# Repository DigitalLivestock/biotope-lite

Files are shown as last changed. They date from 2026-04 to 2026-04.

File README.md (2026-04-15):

# BIOTOPE(LITE)™

> BIOTOPE(LITE)™: a High Precision Environment Monitoring Unit




---

## A Bit of History
I started this project a couple of years ago and almost finished it, but life got in the way. Recently, I decided it was time to tie up the loose ends and complete it. While the initial development was paused, the recent work focused on finalizing the essential functionality. Some cleaning of code and its structure was performed, but some of the hacky parts still remain. The main goal of the project was to build an embedded solution based on an AVR microcontroller, designing and implementing as much of the supporting electronics from scratch as possible.

---

## About

The BIOTOPE(LITE)™ is a high precision monitoring unit for measuring indoor and outdoor temperature, relative humidity and pressure. Measurements are displayed on the built-in LCD screen, presenting current, maximum and minimum for data with smart backlight. Navigation among data is enabled by available buttons. Measured maximum and minimum are automatically restored between power on and -off. Through available settings, it is possible to manually store and reset data.



## Features

* Indoor temperature reading in range (-)40 – 85 °C.
* Indoor pressure readings in range 300 – 1100 hPa.
* Indoor relative humidity as 0 – 100 %.
* Outdoor temperature reading in range (-)25 – 125 °C.
* Minimum and maximum tracking of temperature, humidity and pressure.
* LCD display with timer based backlight.
* Buttons for navigation and configuration.
* Persistent data store and restore between power states.
* Ultra low power consumption at 15mA when idle or 23 mA when active.
* Battery (4 x AA) or wall powered (0.2A/6V via 2.1 mm DC-Jack).

---

## Usage
Choose if you want to use 4 x AA batteries or a compatible wall power adapter capable of supplying at least 0.2A at 6V via DC-Jack (2.1 mm):
* Battery powered: carefully open BIOTOPE(LITE)™ by unscrewing the back panel and inserting 4 x AA batteries into the battery holder.
* Wall power adapter: connect adapter DC-Jack male contact to BIOTOPE(LITE)™ female.
Power-on device by moving switch above DC-Jack female connector. The LCD screen shall light-up showing initial start-up screen. 

The device displays measurement data and configuration options on the LCD screen in the form of frames, among which a user can navigate using buttons. As can be seen in the next figure below, a frame is made up of two rows and there are five buttons available. Buttons consist of UP, DOWN, LEFT, RIGHT, and ENTER—allowing for full access among network of selectable frames, as can be observed in the second figure. Frames can be seen connected to one another via arrows, here representing button actions.



In the following, each frame and their functions are explained more in detail. The identification numbers of each Frame are found in the green boxes inserted at top-right of each frame in the following figure.
* Frame 0.0: Initial – Device name and software version 
* Frame 1.0: Current temperature indoors and outdoors (°C)
* Frame 1.1: Maximum and minimum temperature indoors (°C)
* Frame 1.2: Maximum and minimum temperature outdoors (°C)
* Frame 2.0: Current relative humidity (%) and pressure (hPa) indoors
* Frame 2.1: Maximum and minimum relative humidity indoors (%)
* Frame 2.2: Maximum and minimum pressure indoors (hPa)
* Frame 3.0: Settings menu
* Frame 3.1: Backup all maximum and minimum data using persistent storage when pressing ENTER-button
* Frame 3.2: Reset all maximum and minimum data in persistent storage when pressing ENTER-button



---

## Project Structure

```
biotope-lite/
├── src/
│ └── biotope_lite/
│     ├── biotope_lite.ino
│     ├── biotope_lite_app.h
│     ├── biotope_lite_app.cpp
│     ├── config.h
│     ├── lcd.h 
│     ├── lcd.cpp
│     ├── bme280.h 
│     ├── bme280.cpp
│     ├── ntc.h 
│     ├── ntc.cpp  
│     ├── MCP23016.h
│     ├── MCP23016.cpp
│     ├── twi.h
│     ├── twi.cpp
│     ├── queue.h
│     ├── queue.cpp 
│     └── biotope_manual_rev1.0.odt
├── hardware/
│ └── schematic/
│   ├── biotope_lite_rev1.0.kicad_prl
│   ├── biotope_lite_rev1.0.kicad_pro
│   └── biotope_lite_rev1.0.kicad_sch
├── docs/
│ ├── figures/
│ └── biotope_manual_rev1.0.odt
├── biotope_lite_manual_v1.0.pdf
├── biotope_lite_schematic_rev1.0.pdf
├── LICENSE.md
└── README.md
```

---

## License

This project is licensed under the MIT License – see the LICENSE file for details.

---

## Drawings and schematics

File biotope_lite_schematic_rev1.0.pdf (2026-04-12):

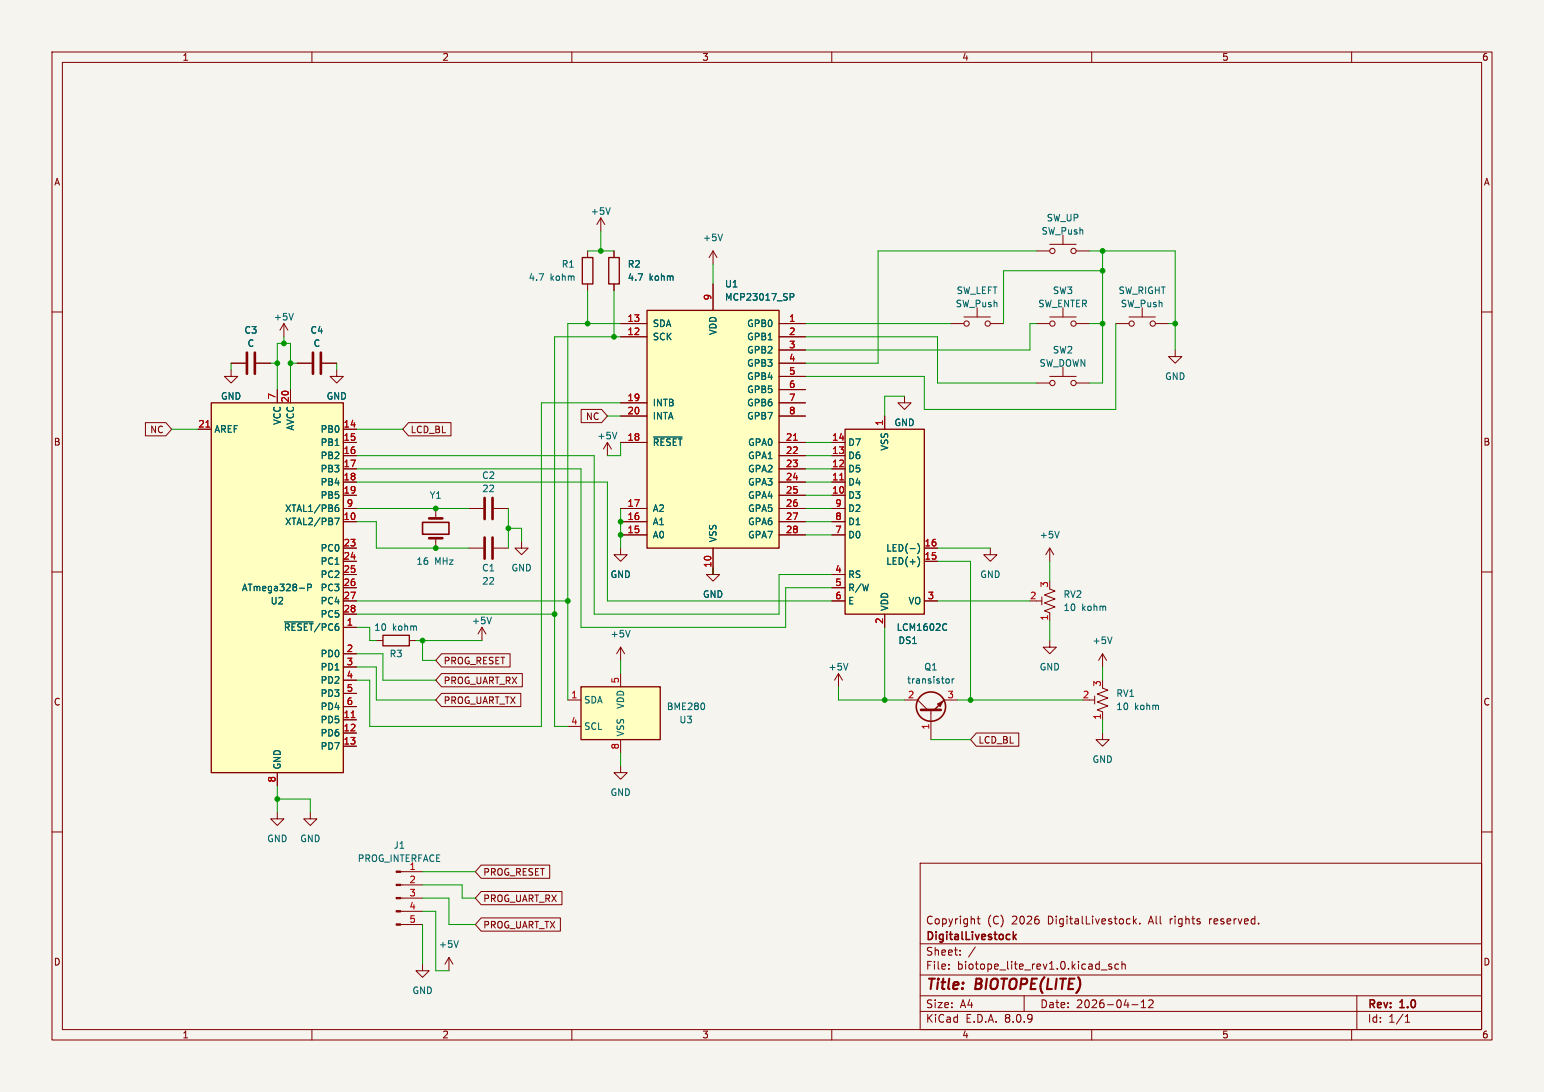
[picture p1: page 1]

Id: 1/1 Title: BIOTOPE(LITE) File: biotope_lite_rev1.0.kicad_sch Sheet: / DigitalLivestock

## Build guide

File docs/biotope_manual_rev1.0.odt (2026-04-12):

BIOTOPE(LITE)™: a High Precision Environment Monitoring Unit

USER GUIDE

Inventor and Author: DigitalLivestock

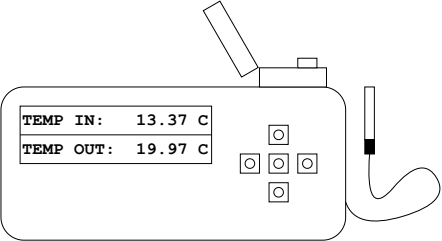
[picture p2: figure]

# 1. Introduction

The BIOTOPE(LITE)™ is a high precision monitoring unit for measuring indoor and outdoor temperature, relative humidity and pressure. Measurements are displayed on the built-in LCD screen, presenting current, maximum and minimum for data with smart backlight. Navigation among data is enabled by available buttons. Measured maximum and minimum are automatically restored between power on and -off. Through available settings, it is possible to manually store and reset data.

# 2. Feature Specification

- Indoor temperature reading in range (-)40 – 85 °C.
- Indoor pressure readings in range 300 – 1100 hPa.
- Indoor relative humidity as 0 – 100 %.
- Outdoor temperature reading in range (-)25 – 125 °C.
- Minimum and maximum tracking of temperature, humidity and pressure.
- LCD display with timer based backlight.
- Buttons for navigation and configuration.
- Persistent data store and restore between power states.
- Ultra low power consumption at 15mA when idle or 23 mA when active.
- Battery (4 x AA) or wall powered (0.2A/6V via 2.1 mm DC-Jack).

# 3. Getting Started

Choose if you want to use 4 x AA batteries or a compatible wall power adapter capable of supplying at least 200mA at 6V via DC-Jack (2.1 mm):

- Battery powered: carefully open BIOTOPE(LITE)™ by unscrewing the back panel and inserting 4 x AA batteries into the battery holder.
- Wall power adapter: connect adapter DC-Jack male contact to BIOTOPE(LITE)™ female.

Power-on device by moving switch above DC-Jack female connector. The LCD screen shall light-up showing initial start-up screen.

# 4. Use

The device displays measurement data and configuration options on the LCD screen in the form of frames, among which a user can navigate using buttons. As can be seen in Figure 1, a frame is made up of two rows and there are five buttons available. Buttons consist of UP, DOWN, LEFT, RIGHT, and ENTER—allowing for full access among network of selectable frames, as can be observed in Figure 2. Frames can be seen connected to one another via arrows, here representing button actions.

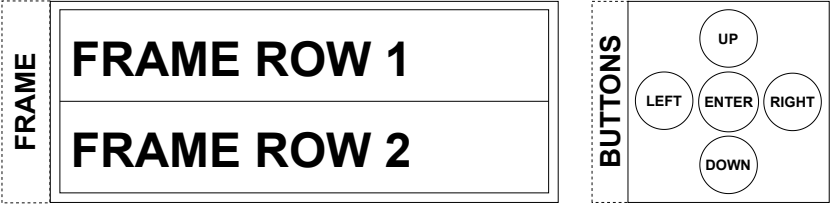
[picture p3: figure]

Figure 1: The so called Frame on the left and buttons to navigate on the right.

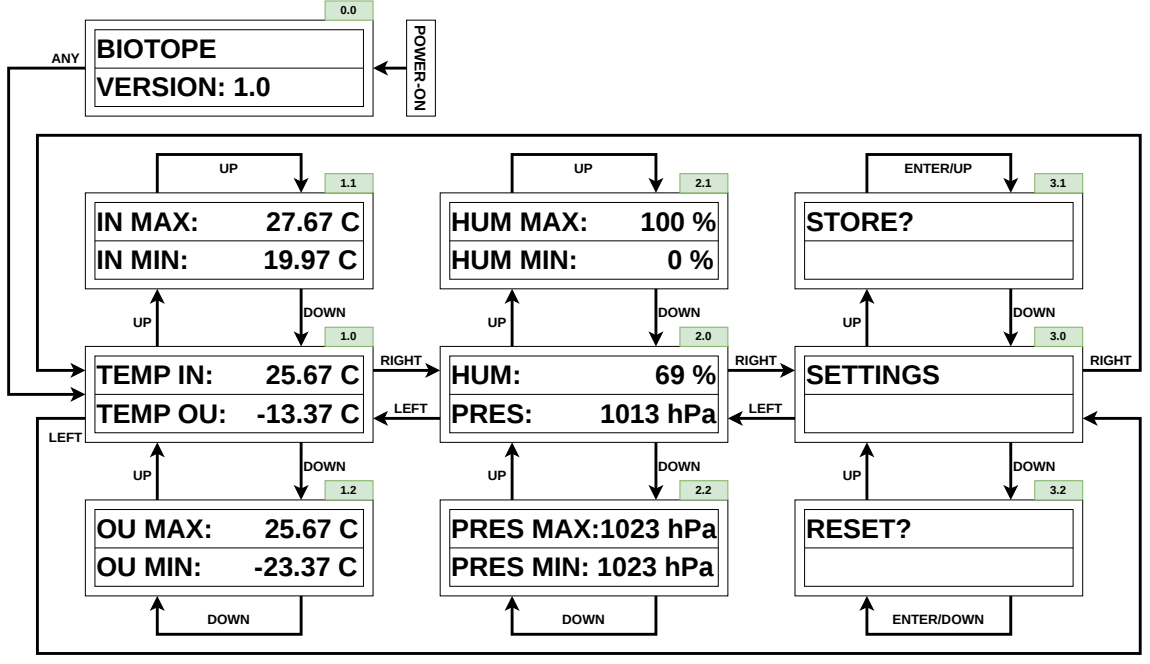
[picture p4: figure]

Figure 2: Frame network and possible navigation paths using button actions.

In the following, each frame and their functions are explained more in detail. The identification numbers of each Frame are found in the green boxes inserted at top-right of each frame in Figure 2.

- Frame 0.0: Initial – Device name and software version
- Frame 1.0: Current temperature indoors and outdoors (°C)
- Frame 1.1: Maximum and minimum temperature indoors (°C)
- Frame 1.2: Maximum and minimum temperature outdoors (°C)
- Frame 2.0: Current relative humidity (%) and pressure (hPa) indoors
- Frame 2.1: Maximum and minimum relative humidity indoors (%)
- Frame 2.2: Maximum and minimum pressure indoors (hPa)
- Frame 3.0: Settings menu
- Frame 3.1: Backup all maximum and minimum data using persistent storage when pressing ENTER-button
- Frame 3.2: Reset all maximum and minimum data in persistent storage when pressing ENTER-button

USER GUIDE BIOTOPE(LITE)

4 Copyright (C) 2026 DigitalLivestock. All rights reserved. v1.0

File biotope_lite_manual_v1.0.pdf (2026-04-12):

USER GUIDE | BIOTOPE(LITE)

# BIOTOPE(LITE)™: a High Precision Environment Monitoring Unit

## USER GUIDE

Inventor and Author: DigitalLivestock

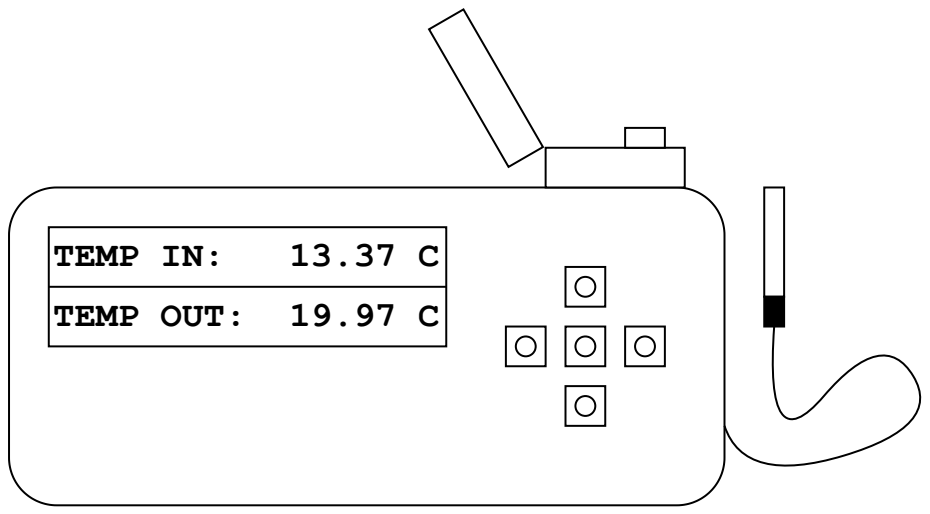
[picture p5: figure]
TEMP IN:; TEMP OUT: 19.97 C

### Table of Contents

## 1. Introduction

The BIOTOPE(LITE)™ is a high precision monitoring unit for measuring indoor and

outdoor temperature, relative humidity and pressure. Measurements are displayed on

the built-in LCD screen, presenting current, maximum and minimum for data with smart

backlight. Navigation among data is enabled by available buttons. Measured maximum

and minimum are automatically restored between power on and -off. Through available

settings, it is possible to manually store and reset data.

1 | Copyright (C) 2026 DigitalLivestock. All rights reserved. | v1.0

## 2. Feature Specification

- Indoor temperature reading in range (-)40 – 85 °C.
- Indoor pressure readings in range 300 – 1100 hPa.
- Indoor relative humidity as 0 – 100 %.
- Outdoor temperature reading in range (-)25 – 125 °C.
- Minimum and maximum tracking of temperature, humidity and pressure.
- LCD display with timer based backlight.
- Buttons for navigation and configuration.
- Persistent data store and restore between power states.
- Ultra low power consumption at 15mA when idle or 23 mA when active.
- Battery (4 x AA) or wall powered (0.2A/6V via 2.1 mm DC-Jack).

## 3. Getting Started

Choose if you want to use 4 x AA batteries or a compatible wall power adapter capable

of supplying at least 200mA at 6V via DC-Jack (2.1 mm):

- Battery powered: carefully open BIOTOPE(LITE)™ by unscrewing the back panel

and inserting 4 x AA batteries into the battery holder.

- Wall power adapter: connect adapter DC-Jack male contact to BIOTOPE(LITE)™

female.

Power-on device by moving switch above DC-Jack female connector. The LCD screen

shall light-up showing initial start-up screen.

## 4. Use

The device displays measurement data and configuration options on the LCD screen in

the form of frames, among which a user can navigate using buttons. As can be seen in

Figure 1, a frame is made up of two rows and there are five buttons available. Buttons

consist of UP, DOWN, LEFT, RIGHT, and ENTER—allowing for full access among network

of selectable frames, as can be observed in Figure 2. Frames can be seen connected to

one another via arrows, here representing button actions.

2 | Copyright (C) 2026 DigitalLivestock. All rights reserved. | v1.0

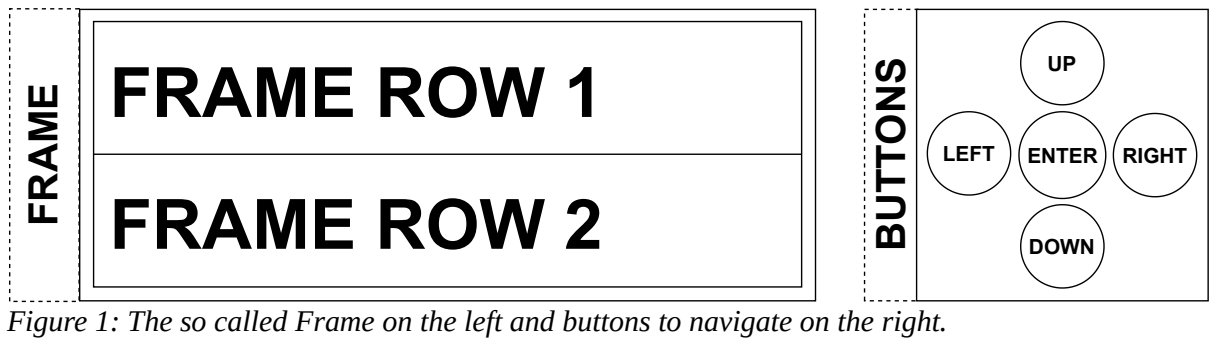
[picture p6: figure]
BUTTONS; FRAME; LEFT; ENTER RIGHT; DOWN; UP FRAME ROW 1; FRAME ROW 2
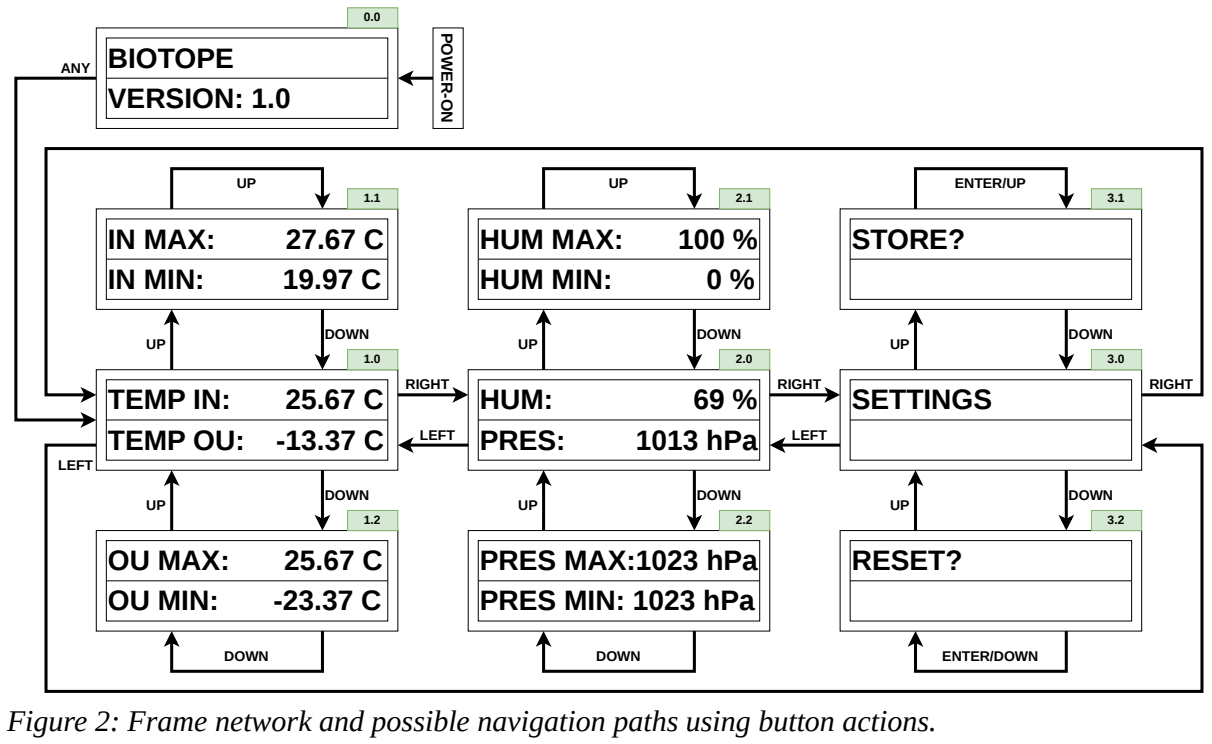
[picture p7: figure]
POWER-ON; TEMP IN:; TEMP OU: -13.37 C; IN MAX:; IN MIN:; OU MAX:; OU MIN:; DOWN; HUM:; PRES:; 1013 hPa; HUM MAX:; HUM MIN:; PRES MAX:1023 hPa PRES MIN: 1023 hPa; RIGHT; SETTINGS; STORE?; RESET?; ENTER/UP; ENTER/DOWN; LEFT; BIOTOPE VERSION: 1.0; ANY

In the following, each frame and their functions are explained more in detail. The

identification numbers of each Frame are found in the green boxes inserted at top-right

of each frame in Figure 2.

- Frame 0.0: Initial – Device name and software version
- Frame 1.0: Current temperature indoors and outdoors (°C)
- Frame 1.1: Maximum and minimum temperature indoors (°C)
- Frame 1.2: Maximum and minimum temperature outdoors (°C)
- Frame 2.0: Current relative humidity (%) and pressure (hPa) indoors
- Frame 2.1: Maximum and minimum relative humidity indoors (%)
3 | Copyright (C) 2026 DigitalLivestock. All rights reserved. | v1.0

Figure 2: Frame network and possible navigation paths using button actions.

Figure 1: The so called Frame on the left and buttons to navigate on the right.

- Frame 2.2: Maximum and minimum pressure indoors (hPa)
- Frame 3.0: Settings menu
- Frame 3.1: Backup all maximum and minimum data using persistent storage when

pressing ENTER-button

- Frame 3.2: Reset all maximum and minimum data in persistent storage when

pressing ENTER-button

4 | Copyright (C) 2026 DigitalLivestock. All rights reserved. | v1.0

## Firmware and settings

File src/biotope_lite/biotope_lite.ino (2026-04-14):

/*****************************************************************************
 * File: biotope_lite.ino
 * Author: DigitalLivesock
 * Date: 2026-02-07
 * Description: Arduino MAIN
/*****************************************************************************
 * Copyright (C) 2026 DigitalLivestock
 *
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
 * You should have received a copy of the GNU Affero General Public License
 * along with this program.  If not, see <https://www.gnu.org/licenses/>.
 *****************************************************************************/

#include "biotope_lite_app.h"

void setup(void)
{
  biotope_app_init();
}

void loop()
{
  biotope_app_main();
}

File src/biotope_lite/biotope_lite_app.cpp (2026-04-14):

/*****************************************************************************
 * File: biotope_lite_app.cpp
 * Author: DigitalLivesock
 * Date: 2026-02-07
 * Description: Biotope Lite MAIN
/*****************************************************************************
 * Copyright (C) 2026 DigitalLivestock
 *
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
 * You should have received a copy of the GNU Affero General Public License
 * along with this program.  If not, see <https://www.gnu.org/licenses/>.
 *****************************************************************************/

#include "biotope_lite_app.h"

state_t *curr_state;

state_t f1, f2, f2_1, f2_2, f3, f3_1, f3_2, f4, f4_1, f4_2;

volatile uint8_t button_pressed = false;

/* Counters acting as timers for sampling and lcd idle: */
volatile uint32_t lcd_idle_timer_sec = 0;
volatile uint32_t sampling_timer_sec = 0;

/* Environmental measurements: */
/* TODO: NEED TO BE ABLE TO TRACK WHERE CURR ADDRESS SPACE IS BETWEEN POWER ON/OFF - a bit more complex than anticipated!) */
volatile float max_temp_in = 0.00;
volatile float min_temp_in = 99.00;

volatile float max_temp_out = 0.00;
volatile float min_temp_out = 99.00;

volatile float max_pres = 0.00;
volatile float min_pres = 9999.00;

volatile float max_hum = 0.00;
volatile float min_hum = 100.00;

char frame_line_text[20][17] = {
  "BIOTOPE(LITE)   ",
  "Rev: 1.2        ",

  "TEMP IN: 00.00 C",
  "TEMP OU: 00.00 C",

  "TEMP HI: 00.00 C",
  "TEMP HO: 00.00 C",

  "TEMP LI: 00.00 C",
  "TEMP LO: 00.00 C",

  "HUMI:          %",
  "PRES:        hPa",

  "HUMI H:        %",
  "HUMI L:        %",

  "PRE H:       hPa",
  "PRE L:       hPa",

  "SETTINGS        ",
  "                ",

  "BACKUP?         ",
  "                ",

  "RESET?          ",
  "                "
};

/* Setup event queue: */
uint8_t queue_buf[50];

void biotope_app_init(void)
{
  #if SERIAL_PRINT_DEBUG
    Serial.begin(9600);
  #endif

  queue_init(queue_buf, 20);

  /* Fetch history from biotope_eeprom: */
  restore_data_from_eeprom();

  /* Set transition paths for all states: */
  state_init();
  
  /* Initialize TWI and wait: */
  twi_init();
  delay(50);

  /* Configure LCD LED pin: */
  pinMode(LCD_ACTIVE_PIN, OUTPUT);

  /* Configure interrupt pin for buttons: */
  pinMode(BUTTON_INT_PIN, INPUT_PULLUP);

  /* Configure LCD control pins: */
  pinMode(LCD_ENABLE_PIN, OUTPUT);
  pinMode(LCD_RS_PIN, OUTPUT);
  pinMode(LCD_RW_PIN, OUTPUT);

  digitalWrite(LCD_ENABLE_PIN, LOW);
  digitalWrite(LCD_RS_PIN, LOW);
  digitalWrite(LCD_RW_PIN, LOW);

  /* Enable BANK = 1 on IOE: */
  twi_write(IOEADDR, 0x0A, 0b10000000);

  /* Set Port A to output on IOE: */
  twi_write(IOEADDR, IODIRA, 0x00);

  /* Set Port B to out/input on IOE: */
  twi_write(IOEADDR, IODIRB, 0b00011111);

  /* Configure pull-up on IOE B port: */
  twi_write(IOEADDR, GPPUB, 0b00011111);
  
  /* Configure interrupt on IOE B port: */
  twi_write(IOEADDR, GPINTENB, 0b00011111);
  twi_write(IOEADDR, DEFVALB, 0b00011111);
  twi_write(IOEADDR, INTCONB, 0b00011111);

  /* Setup LCD and defaults: */
  lcd_init();
  cursor_off();
  digitalWrite(LCD_ACTIVE_PIN, HIGH);
  curr_state = &f1;
  put_curr_frame();

  /* Initialize BME280 sensor over: TWI */
  bme_init();

  /* Initialize NTC sensor: ADC */
  ntc_init(NTC_PIN);

  /* Setup Watchdog as sampling timer: */
  wdt_init();
  
  /* Configure button interrupts: */
  attachInterrupt(digitalPinToInterrupt(BUTTON_INT_PIN), check_button, FALLING);

  /* Configure sleep mode: power-down */
  SMCR |= (0<<SM2) | (1<<SM1) | (0<<SM0);
  
  /* Clear button interrupts in IO-expander: */
  clear_int_reg();
  
  /* Enable global interrupts: */
  sei();

  /* Do initial sampling of all: */
  queue_put(TEMP);
  queue_put(HUM);
  queue_put(PRES);

  PRINTLN(SRC_VERSION);
  PRINTLN("SETUP COMPLETE");
}

void frame_update_temperature(const float temp_in, const float temp_out)
{
  String curr_temp_in_str = String(temp_in);
  String max_temp_in_str = String(max_temp_in);
  String min_temp_in_str = String(min_temp_in);

  String curr_temp_out_str = String(temp_out);
  String max_temp_out_str = String(max_temp_out);
  String min_temp_out_str = String(min_temp_out);

  /* Clear old data between description and unit: */
  for (int i = 0; i < 6; i++)
  {
    f2.line0[i+9] = ' ';
    f2_1.line0[i+8] = ' ';
    f2_2.line0[i+8] = ' ';

    f2.line1[i+9] = ' ';
    f2_1.line1[i+8] = ' ';
    f2_2.line1[i+8] = ' ';
  }

  for (int i = 0; i < curr_temp_in_str.length(); i++) {
    f2.line0[i+9] = curr_temp_in_str[i];
    f2_1.line0[i+9] = max_temp_in_str[i];
    f2_2.line0[i+9] = min_temp_in_str[i];
  }

  for (int i = 0; i < curr_temp_out_str.length(); i++) {
    f2.line1[i+9] = curr_temp_out_str[i];
    f2_1.line1[i+9] = max_temp_out_str[i];
    f2_2.line1[i+9] = min_temp_out_str[i];
  }
  
  if (curr_state == &f2) {
    put_string_at(&curr_temp_in_str[0], curr_temp_in_str.length(), 0, 9);
    put_string_at(&curr_temp_out_str[0], curr_temp_out_str.length(), 1, 9);
  }
}

void frame_update_humidity(const float hum)
{
  String curr_hum_str = String(hum);
  String max_hum_str = String(max_hum);
  String min_hum_str = String(min_hum);

  /* Clear old data between description and unit: */
  for (int i = 0; i < 6; i++)
  {
    f3.line1[i+6] = ' ';
    f3_1.line0[i+8] = ' ';
    f3_1.line1[i+8] = ' ';
  }

  for (int i = 0; i < curr_hum_str.length(); i++) {
    f3.line0[i+6] = curr_hum_str[i];
    f3_1.line0[i+8] = max_hum_str[i];
    f3_1.line1[i+8] = min_hum_str[i];
  }

  if (curr_state == &f3)
    put_string_at(&curr_hum_str[0], curr_hum_str.length(), 0, 6);
}

void frame_update_pressure(const float pres)
{
  String curr_pres_str = String((int)pres);
  String max_pres_str = String((int)max_pres);
  String min_pres_str = String((int)min_pres); //TODO: does not look required...

  /* Clear old data between description and unit: */
  for (int i = 0; i < 4; i++)
  {
    f3.line1[i+6] = ' ';
    f3_2.line0[i+7] = ' ';
    f3_2.line1[i+7] = ' ';
  }

  for (int i = 0; i < curr_pres_str.length(); i++) {
    f3.line1[i+6] = curr_pres_str[i];
    f3_2.line0[i+7] = max_pres_str[i];
    f3_2.line1[i+7] = min_pres_str[i];
  }

  if (curr_state == &f3)
    put_string_at(&curr_pres_str[0], curr_pres_str.length(), 1, 6);
}
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

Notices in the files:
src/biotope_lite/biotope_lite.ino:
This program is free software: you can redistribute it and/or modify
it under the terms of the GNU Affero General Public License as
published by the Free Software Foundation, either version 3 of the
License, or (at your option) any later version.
